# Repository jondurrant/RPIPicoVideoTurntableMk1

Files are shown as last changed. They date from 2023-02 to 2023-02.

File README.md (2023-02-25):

# RPIPicoVideoTurntableMk1
RPI Pico Video Turntable Mk1. Vidio on this project is available at [https://youtube.com/@drjonea](https://youtube.com/@drjonea).

Still images are boring and when they are PCB or breadboard sometimes dificult to understand from one angle. This project is a controlled turntable for small scale video work on my projects. 

## Features

**Lighting** Uses a strip of WS2812B LEDs to illuminate the photo area. Controlled in terms of Hue, Saturation and Value.

**Calibration** Self calibrating turn table driven by a 28BYJ-48 stepper motor

**Menu** Simple menu displayed on a OLED display and controled through a Rotary Encoder.

**Sequence** Switch 1 moves the turntable to start possition by shortest route and then moves to the end possition in the direction and speed set in the configuration. Good for setup and repeat takes of the same shot

**Stop** Switch 2 stops the turntable.

**Continuous Rotation** Switch 3 provides continuous rotation and the currently configured speed. Short press is clockwise, long press is counterclockwise.

**Reset** Switch 4 resets the turntable

**Pico Reset** Switch 5 is the Pico Reset.

## Schematic and PCB

KiCad files have been included in the Schematic folder.

PDF version of the schematic is also included.

Gerb files are included in the PCB folder 

## 3D Models

OpenSCAD project is in the folder 3DModels. You will need two supporting libraries.

Download [gears.scad](https://www.thingiverse.com/thing:4194148/files)

Download [stepper.scad](https://www.thingiverse.com/thing:4031757/files)

## Libraries

+ [FreeRTOS Kernel](https://github.com/FreeRTOS/FreeRTOS-Kernel)
+ [PicoLED](https://github.com/ForsakenNGS/PicoLED)
+ [pico-ssd1306](https://github.com/daschr/pico-ssd1306)

## Clone and Build

```
git clone --recurse-submodules https://github.com/jondurrant/RPIPicoVideoTurntableMk1
cd RPIPicoVideoTurntableMk1
mkdir build
cd build
cmake ..
make
```

## Links

+ Further YouTube projects on my channel [YouTube @DrJonEa](https://youtube.com/@drjonea).
+ Blogs at [DrJonEa.co.uk](https://drjonea.co.uk/IoT)
+ RPI Pico Courses at [Udemy @DrJonEa](https://drjonea.co.uk/training/)

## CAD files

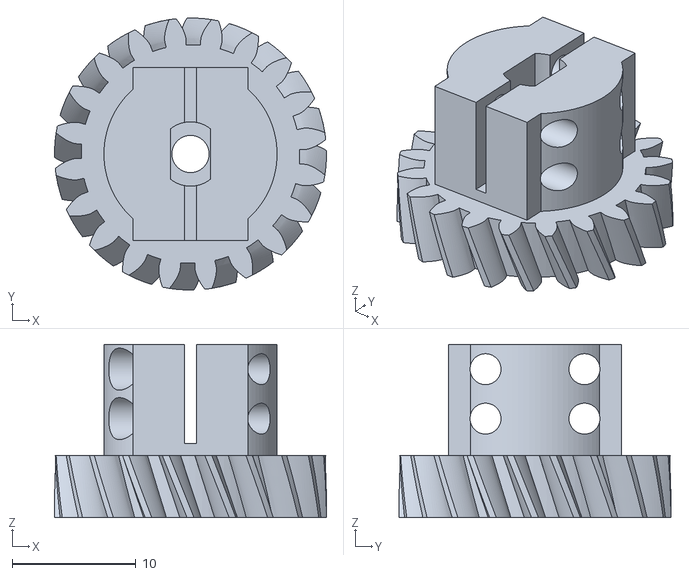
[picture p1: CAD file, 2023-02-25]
3DModels/driveCog.stl
22.0 x 22.0 x 14.0

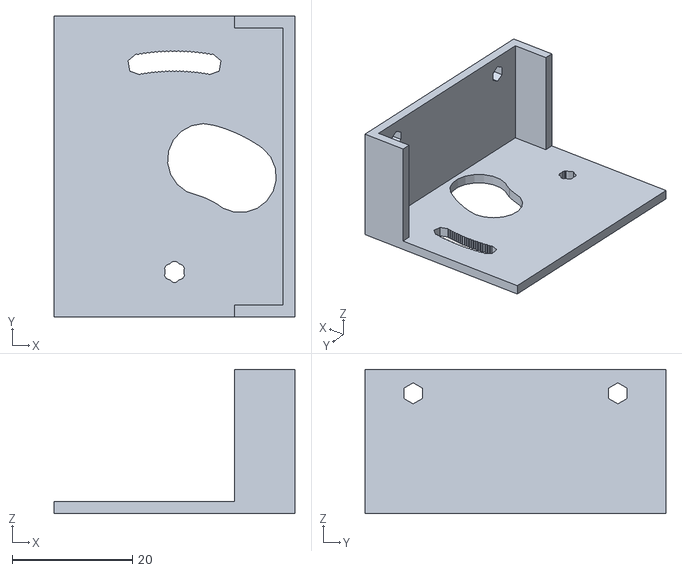
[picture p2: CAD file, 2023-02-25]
3DModels/motorMount.stl
40.0 x 50.0 x 24.0

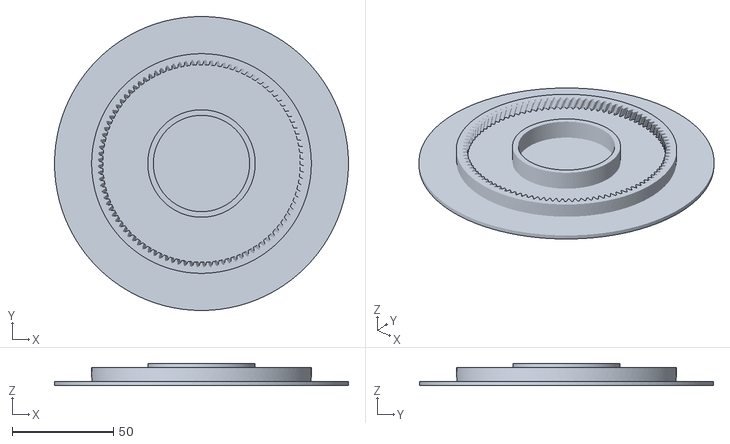
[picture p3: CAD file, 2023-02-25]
3DModels/table.stl
145.0 x 145.0 x 11.0

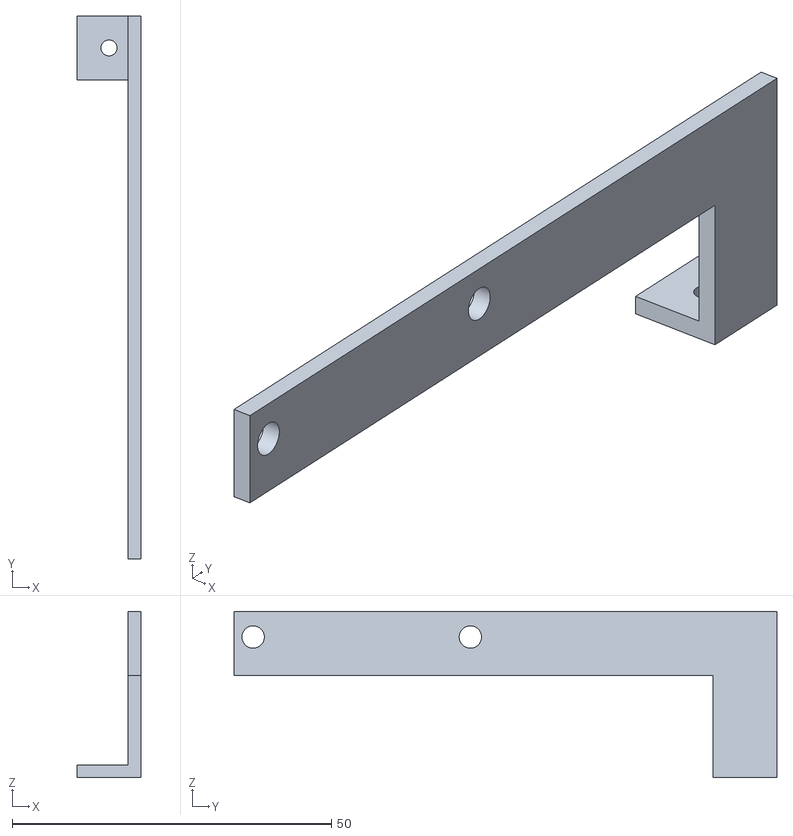
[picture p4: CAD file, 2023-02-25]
3DModels/sensorBracket.stl
10.0 x 85.0 x 26.0

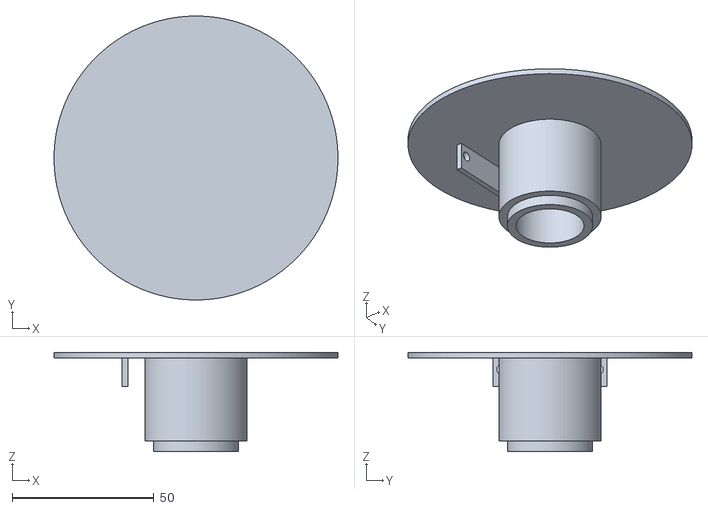
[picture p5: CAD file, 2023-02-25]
3DModels/base.stl
100.0 x 100.0 x 35.0

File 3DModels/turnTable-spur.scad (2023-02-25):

use <gears.scad>
use <stepper.scad>

THICK = 2;
M5=5.5;
M4=4.5;
M3=3.5;
M2=2.5;
M3INSERT=3.7;
M2INSERT=3.4;


Module = 1;
width = 5.0; // 0.01
teeth = 30;
bore = 3; // 0.01
straight = false;

/* [Advanced Parameters] */
hub = true;
hub_diameter = 6; // 0.01
hub_thickness = 5; // 0.01
// (Weight optimization if applicable)
optimized = false;
pressure_angle = 20; // 0.01
helix_angle = 20; // 0.01
clearance = 0.05; // 0.01

/* [Multi-gear configurations] */
idler_teeth = 100;//36;
idler_bore = 3; // 0.01
assembled = true;

/* [Rack parameters] */
rack_length = 50; // 0.01
rack_height = 4; // 0.01

/* [Worm parameters] */
// Worm lead angle                                                                (For final worm diameter, see also number of starts.)
lead_angle = 4; // 0.01
// Number of starts                                                                (For final worm diameter, see also lead angle.)
worm_starts = 1;
// Worm bore                                             (Please note: The bore in Basic Gear Parameters is used for the bore of the worm gear, not the worm.)
worm_bore = 3; // 0.01
worm_length = 6; // 0.01

/* [Bevel gear parameters] */
bevel_angle = 45; // 0.01
bevel_width = 5; // 0.01
shaft_angle = 90; // 0.01

/* [Annular/internal gear parameters] */
rim_width = 3; // 0.01

/* [Planetary gear parameters] */
solar_teeth = 20;
planet_teeth = 10;
number_of_planets = 3;


module customizer_separator() {}

finalHelixAngle = straight ? 0 : helix_angle;
final_hub_diameter = hub ? hub_diameter : 0;
final_hub_thickness = hub ? hub_thickness : 0;

$fn = 96;

/*
 stirnrad (modul=Module, zahnzahl=teeth, breite=width, bohrung=bore, nabendurchmesser=final_hub_diameter, nabendicke=final_hub_thickness, eingriffswinkel=pressure_angle, schraegungswinkel=finalHelixAngle, optimiert=optimized);

*/


/*
kegelrad(modul=Module, zahnzahl=teeth,  teilkegelwinkel=bevel_angle, zahnbreite=bevel_width, bohrung=bore, eingriffswinkel=pressure_angle, schraegungswinkel=finalHelixAngle);

*/

/*
kegelradpaar(modul=Module, zahnzahl_rad=idler_teeth, zahnzahl_ritzel=teeth, achsenwinkel=shaft_angle, zahnbreite=bevel_width, bohrung_rad=idler_bore, bohrung_ritzel=bore, eingriffswinkel=pressure_angle, schraegungswinkel=finalHelixAngle, zusammen_gebaut=assembled);
*/

//cylinder(h=1, d=100, center=true);



mainBearing=[30,47,9];
baseH=40;




driveCog();

color("#A0FFA0")motorMount();
table();
color("#A0A0FF")base();

translate([0,0, mainBearing[2]/2])bearing30x47x9();
motor();


sensor();




//Test outer bearing
/*
intersection(){
    table();
    cylinder(d=60, h= 30, center=true);
}
*/


//Test inner bearing

/*
intersection(){
    base();
    cylinder(d=100, h= 30, center=true);
}
*/



module bearing30x47x9(){
    color("#505050"){
        difference(){
            cylinder(d=mainBearing[1], h = mainBearing[2], center=true);
            cylinder(d=mainBearing[0], h = mainBearing[2]*2, center=true);
        }
    }
}


module driveCog(){
    driveTeeth = 20;
    translate([-39,0,1]){
        stirnrad (modul=Module, zahnzahl=driveTeeth, breite=width, bohrung=bore, nabendurchmesser=final_hub_diameter, nabendicke=0, eingriffswinkel=pressure_angle, schraegungswinkel=finalHelixAngle, optimiert=optimized);
    }
    
    translate([-39,-8,18]){
        rotate([0,180,0])
            hub_28byj48();
    }
}




module table(){
    bearingShrink=0.5;
    translate([0,0,0])
        hohlrad (modul=Module, zahnzahl=idler_teeth, breite=width, randbreite=rim_width, eingriffswinkel=pressure_angle, schraegungswinkel=finalHelixAngle);
    
    translate([0,0,THICK/-2-2])
            cylinder(h=THICK, d=145, center=true);
    
    translate([0,0,THICK/-2])
        difference(){
            cylinder(h=THICK, d=108, center=true);
            cylinder(h=THICK*3, d=106, center=true);
        }
    
    
    difference(){
        translate([0,0,mainBearing[2]/2-2])
            cylinder(h=mainBearing[2], d=mainBearing[1]+THICK*3, center=true);
        cylinder(d=mainBearing[1]+ bearingShrink, h=mainBearing[2]*4, center=true);
    }
         
}




module motor(){
    
    //translate([-39+8,0,18]){
    translate([-39-8,0,18]){

        rotate([0, 0,0]) rotate([0,0,-90]) stepper_28byj48();
    }
}


module cutout_28byj48(){
    //Side M3 Bolts
    for (i=[-1, 1]){
        translate([17.5 * i,0,0]){
            cylinder(d=M3, h=THICK*3, center=true);
        }
    }
    
    translate([0,8,0]){
        cylinder(d=12, h=THICK*3, center=true);
    }
}


module hub_28byj48(){
    spindleD = 5.2;
    spindleX = 3.2;
    hubLen = 10;
    hubDiam = 14;
    translate([0, 8, THICK*1.5 + hubLen/2]){
        difference(){
            union(){
                cylinder(d=hubDiam, h=hubLen, center=true);
                cube([hubDiam/1.5, hubDiam , hubLen], center=true);
            }
            
            //Shaft
            intersection(){
                cylinder(d=spindleD, h=hubLen+THICK, center=true);
                cube([spindleX, hubDiam,hubLen+THICK], center=true);
            }
            
        
        
            // M2 Holes
            for (i=[-1,1]){
                translate([0, i*4, -3]){
                    rotate([0,90,0]) {
                        cylinder(d=M2, h= hubDiam *2, center=true);
                        translate([0,0,hubDiam/2])
                            cylinder(d=M2INSERT, 8, center=true);
                    }
                }
                translate([0, i*4, 1]){
                    rotate([0,90,0]){
                        cylinder(d=M2, h= hubDiam *2, center=true);
                        translate([0,0,hubDiam/2])
                            cylinder(d=M2INSERT, 8, center=true);
                    }
                }
            }
            
            
            //Slot
            translate([0,0,-2]){
                cube([1, hubDiam*1.5, hubLen], center=true);
            }
            
        }
        
    }
}


module base(){
    edge = [-34.5,0,45-18];
    bearingShrink=0;
    
    
    
    //Base Plate
    translate([0,0,baseH]) {
        cylinder(h=THICK, d=100, center=true);
    }
    
    //Mainbearing Post
    translate([0,0,(baseH + mainBearing[2])/2-THICK]){
        difference(){
            //Outer Wall
            cylinder(d=mainBearing[0]+THICK*3, h = baseH - mainBearing[2] + THICK, center=true);
            //Seat
            translate([0,0,baseH/-2+THICK*2.5]) difference(){
                cylinder(d=mainBearing[1]+THICK*2, h = mainBearing[2]/2, center=true);
                cylinder(d=mainBearing[0]-bearingShrink, h = mainBearing[2]/2, center=true);
            }
            
            //Inner
            cylinder(d=mainBearing[0]-THICK*3, h = baseH *2, center=true);
        }
    }
    
    
    //Motor Plate
    translate([-47,0, baseH]) {
        translate([22,0,(10+THICK)/(-2)]){
            difference(){
                cube([THICK, 40, 10], center=true);
                for (y=[-17,17])translate([0,y,1]){
                    rotate([0,90,0])
                        cylinder(d=M3, h=THICK*4, center=true);
                }
            }
        }
    }
   
}

module motorMount(){
    
    
    //Motor Mount
    motorH=24;
    translate([-47,0, baseH]) {
        translate([0,0,(motorH+THICK)/(-2)]){
            difference(){
                cube([40,50,motorH], center=true);
                translate([THICK*-1,0,THICK]){
                    cube([40,50-THICK*2,motorH], center=true);
                }
                translate([THICK*-5,0,THICK]){
                    cube([40,55-THICK*2,motorH], center=true);
                }
                
                translate([0,0,motorH/(-2)]){
                    rotate([0,0,-90]){
                        cutout_28byj48();
                        for (i=[-10:1:10]){
                            rotate_about([0,0,i],p=[17.5,0,0]){
                                cutout_28byj48();
                            }
                        }
                    }
                }
                
                //Bolt holes
                translate([40/2,0,motorH/(2) - THICK*2]){
                    for (y=[-17,17])translate([0,y,0]){
                        rotate([0,90,0])
                            cylinder(d=M3, h=THICK*4, center=true);
                    }
                }
            }
        }
    }
}

module rotate_about(a, v, p=[0,0,0]) {
     translate(p) rotate(a,v) translate(-p) children();
}


module m4Spacer(){
    difference(){
        cylinder(d=7, h=4, center=true);          
        cylinder(d=M4, h=40, center=true);     
    }
}
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

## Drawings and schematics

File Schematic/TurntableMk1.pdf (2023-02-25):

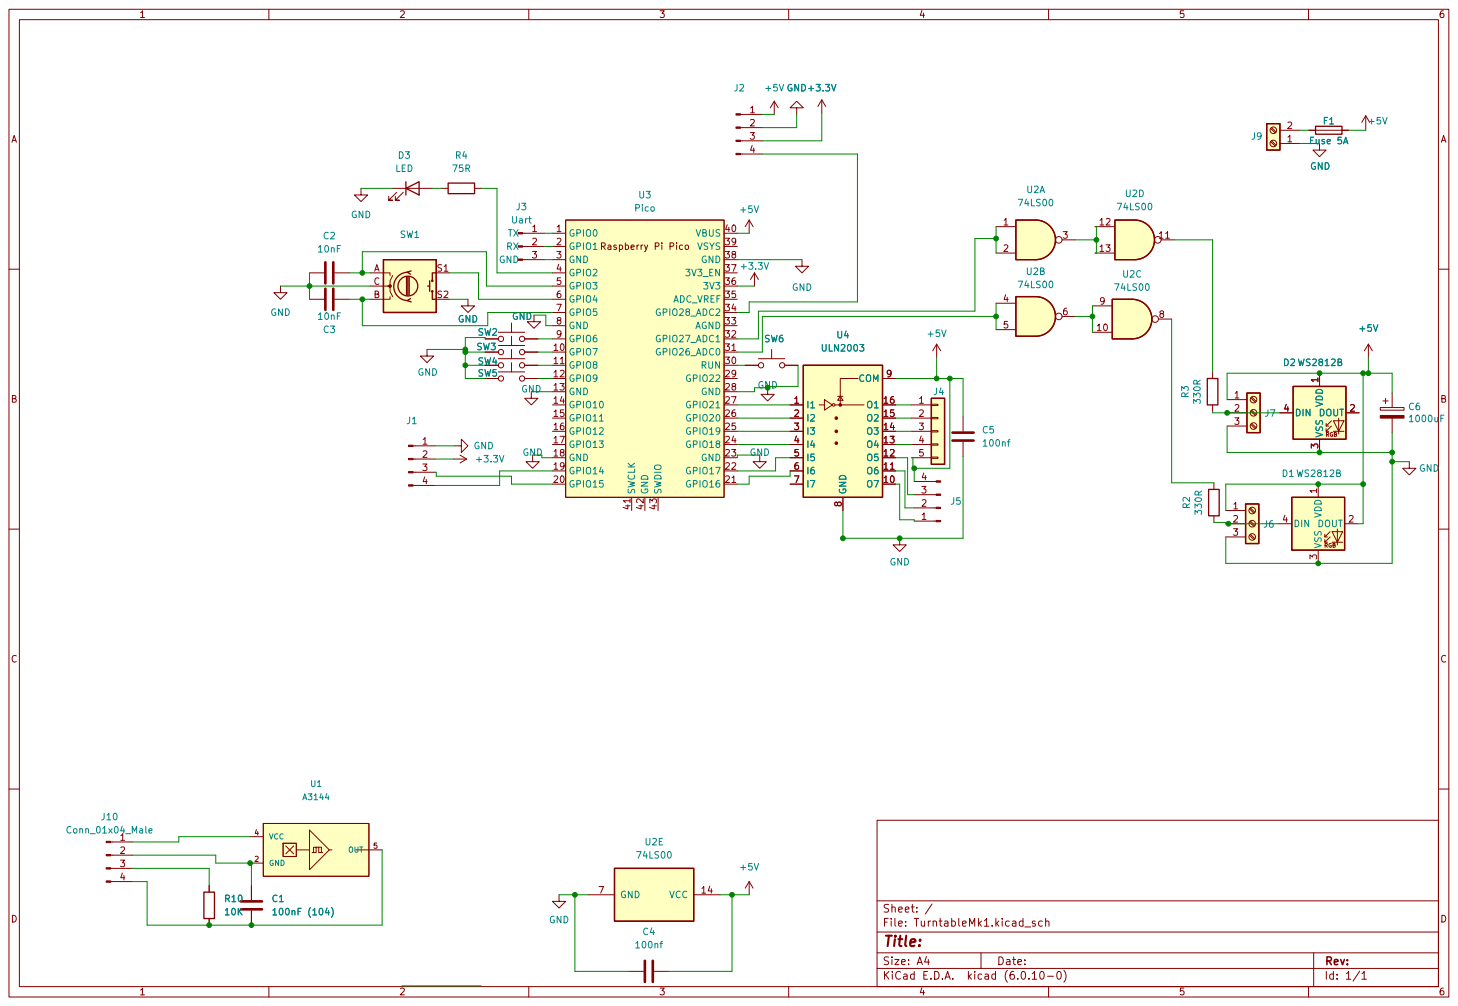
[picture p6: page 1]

I4 4 | 4
I5 5 | 5

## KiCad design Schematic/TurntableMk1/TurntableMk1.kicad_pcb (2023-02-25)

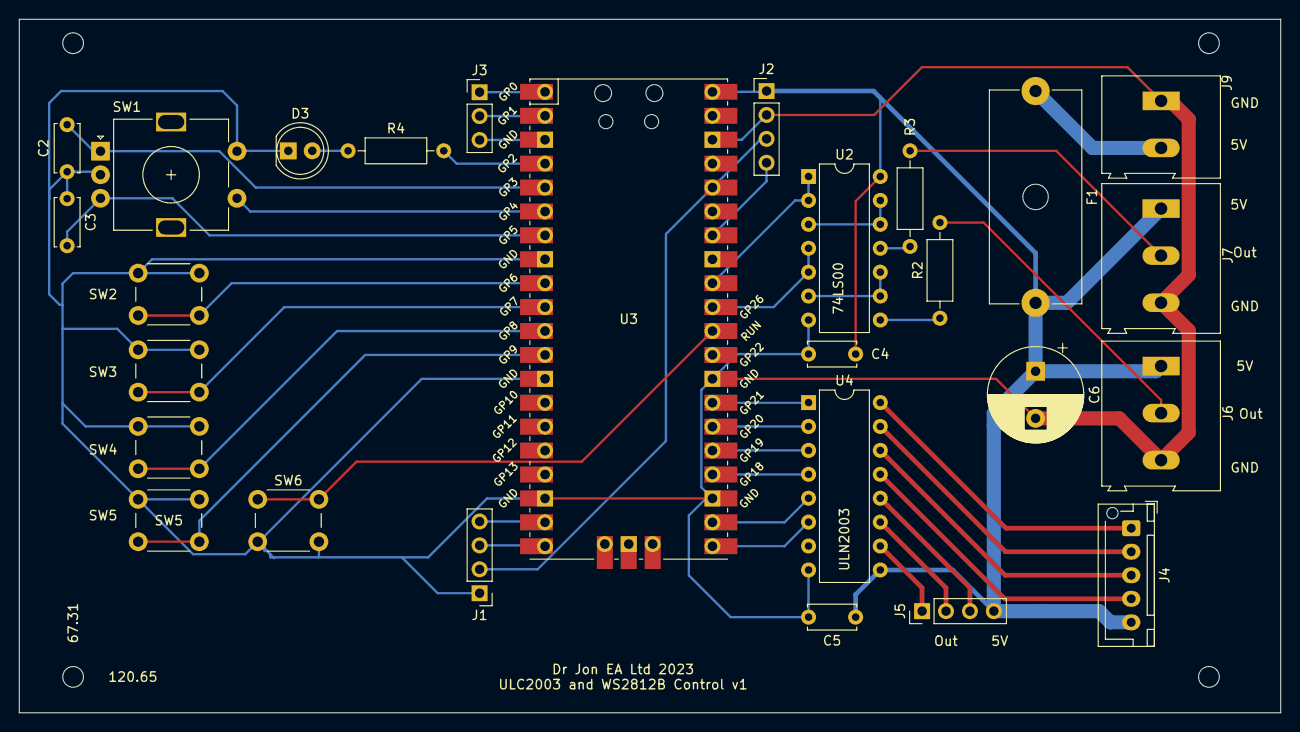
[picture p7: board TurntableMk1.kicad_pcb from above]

Board: 2 copper layers, 134.0 x 73.7 mm, 27 parts (0 on the bottom side), 41 nets.

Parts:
C2, C3: 10nF; C_Disc_D5.0mm_W2.5mm_P5.00mm
C4, C5: 100nf; C_Disc_D5.0mm_W2.5mm_P5.00mm
C6: 1000uF; CP_Radial_D10.0mm_P5.00mm
D3: LED; LED_D5.0mm
F1: Fuse 5A; Fuseholder_Cylinder-5x20mm_Schurter_0031_8201_Horizontal_Op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
J1, J2, J5: Conn_01x04_Male; PinHeader_1x04_P2.54mm_Vertical
J3: Uart; PinHeader_1x03_P2.54mm_Vertical
J4: Conn_01x05; JST_XH_B5B-XH-AM_1x05_P2.50mm_Vertical
J6, J7: Screw_Terminal_01x03; TerminalBlock_Altech_AK300-3_P5.00mm
J9: Screw_Terminal_01x02; TerminalBlock_Altech_AK300-2_P5.00mm
R2, R3: 330R; R_Axial_DIN0207_L6.3mm_D2.5mm_P10.16mm_Horizontal
R4: 75R; R_Axial_DIN0207_L6.3mm_D2.5mm_P10.16mm_Horizontal
SW1: RotaryEncoder_Switch; RotaryEncoder_Alps_EC11E-Switch_Vertical_H20mm
SW2, SW3, SW4, SW5, SW6: SW_Push; SW_PUSH_6mm
U2: 74LS00; DIP-14_W7.62mm
U3: Pico; RPi_Pico_SMD_TH
U4: ULN2003; DIP-16_W7.62mm

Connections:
+3.3V: J1.2, J2.3, U3.36 (3V3)
+5V: C4.1, C5.1, C6.1, F1.2, J2.1, J4.5, J5.4, J6.1, J7.1, U2.14 (VCC), U3.40 (VBUS), U4.9 (COM)
GND: C2.1, C3.1, C4.2, C5.2, C6.2, D3.1 (K), J1.1, J2.2, J6.3, J7.3, J9.1, SW1.C, SW1.S2, SW2.1, SW3.1, SW4.1, SW5.1, SW6.2, U2.7 (GND), U3.8 (GND), U3.13 (GND), U3.18 (GND), U3.23 (GND), U3.28 (GND), U3.38 (GND), U4.8 (GND)
unnamed: C2.2, SW1.A, U3.5 (GPIO3)
unnamed: C3.2, SW1.B, U3.7 (GPIO5)
unnamed: J6.2, R2.2
unnamed: J7.2, R3.2
unnamed: D3.2 (A), R4.1
unnamed: F1.1, J9.2
unnamed: J1.3, U3.20 (GPIO15)
unnamed: J3.1 (TX), U3.1 (GPIO0)
unnamed: J3.2 (RX), U3.2 (GPIO1)
unnamed: J3.3 (GND), U3.3 (GND)
unnamed: J4.1, U4.16 (O1)
unnamed: J4.2, U4.15 (O2)
unnamed: J4.3, U4.14 (O3)
unnamed: J4.4, U4.13 (O4)
unnamed: J5.1, U4.10 (O7)
unnamed: J5.2, U4.11 (O6)
unnamed: J5.3, U4.12 (O5)
unnamed: R2.1, U2.8
unnamed: R3.1, U2.11
unnamed: R4.2, U3.4 (GPIO2)
unnamed: SW1.S1, U3.6 (GPIO4)
unnamed: SW2.2, U3.9 (GPIO6)
unnamed: SW3.2, U3.10 (GPIO7)
unnamed: SW4.2, U3.11 (GPIO8)
unnamed: SW5.2, U3.12 (GPIO9)
unnamed: SW6.1, U3.30 (RUN)
unnamed: U2.1, U2.2, U3.32 (GPIO27_ADC1)
unnamed: U2.4, U2.5, U3.31 (GPIO26_ADC0)
unnamed: U2.6, U2.9, U2.10
unnamed: U2.3, U2.12, U2.13
unnamed: J1.4, U3.19 (GPIO14)
unnamed: U3.21 (GPIO16), U4.6 (I6)
unnamed: U3.22 (GPIO17), U4.5 (I5)
unnamed: U3.24 (GPIO18), U4.4 (I4)
unnamed: U3.25 (GPIO19), U4.3 (I3)
unnamed: U3.26 (GPIO20), U4.2 (I2)
unnamed: U3.27 (GPIO21), U4.1 (I1)
unnamed: J2.4, U3.34 (GPIO28_ADC2)

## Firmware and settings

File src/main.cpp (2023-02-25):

/***
 * Control Turntable and Led Lights
 *
 * Uses FreeRTOS Task
 * Jon Durrant
 * 15-Aug-2022
 */


#include "pico/stdlib.h"

#include "FreeRTOS.h"
#include "task.h"
#include <stdio.h>

#include "BlinkAgent.h"
#include "Stepper28BYJ.h"

#include <PicoLed.hpp>
#include "OledDisplay.h"

#include "RotEncListener.h"
#include "RotEncAgent.h"

#include "UI.h"


//Standard Task priority
#define TASK_PRIORITY		( tskIDLE_PRIORITY + 1UL )

//LED PAD to use
#define LED_PAD			2
#define LEDS_PAD		27

//Rotary Encoder
#define ROTENC_SW_PAD	4
#define ROTENC_A_PAD	3
#define ROTENC_B_PAD	5
#define ROTENC_COUNT	20


//Switches
#define SW1_PAD			6
#define SW2_PAD			7
#define SW3_PAD			8
#define SW4_PAD			9


//OLED I2C
#define OLED_SDA_PAD	14
#define OLED_SDL_PAD	15

//Stepper
#define STEPPER_A_PAD		18
#define STEPPER_B_PAD		19
#define STEPPER_C_PAD		20
#define STEPPER_D_PAD		21
#define STEPPER_HALL_PAD	28

/***
 * Debug function to look at Task Stats
 */
void runTimeStats(   ){
	TaskStatus_t *pxTaskStatusArray;
	volatile UBaseType_t uxArraySize, x;
	unsigned long ulTotalRunTime;


   // Get number of takss
   uxArraySize = uxTaskGetNumberOfTasks();
   printf("Number of tasks %d\n", uxArraySize);

   //Allocate a TaskStatus_t structure for each task.
   pxTaskStatusArray = (TaskStatus_t *)pvPortMalloc( uxArraySize * sizeof( TaskStatus_t ) );

   if( pxTaskStatusArray != NULL ){
      // Generate raw status information about each task.
      uxArraySize = uxTaskGetSystemState( pxTaskStatusArray,
                                 uxArraySize,
                                 &ulTotalRunTime );

	 // Print stats
	 for( x = 0; x < uxArraySize; x++ )
	 {
		 printf("Task: %d \t cPri:%d \t bPri:%d \t hw:%d \t%s\n",
				pxTaskStatusArray[ x ].xTaskNumber ,
				pxTaskStatusArray[ x ].uxCurrentPriority ,
				pxTaskStatusArray[ x ].uxBasePriority ,
				pxTaskStatusArray[ x ].usStackHighWaterMark ,
				pxTaskStatusArray[ x ].pcTaskName
				);
	 }


      // Free array
      vPortFree( pxTaskStatusArray );
   } else {
	   printf("Failed to allocate space for stats\n");
   }

   //Get heap allocation information
   HeapStats_t heapStats;
   vPortGetHeapStats(&heapStats);
   printf("HEAP avl: %d, blocks %d, alloc: %d, free: %d\n",
		   heapStats.xAvailableHeapSpaceInBytes,
		   heapStats.xNumberOfFreeBlocks,
		   heapStats.xNumberOfSuccessfulAllocations,
		   heapStats.xNumberOfSuccessfulFrees
		   );
}


/***
 * Main task to boot the other Agents
 * @param params - unused
 */
void mainTask(void *params){
	BlinkAgent blink(LED_PAD);

	printf("Boot task started\n");


	blink.start("Blink", TASK_PRIORITY);


	Stepper28BYJ stepper(
			STEPPER_A_PAD,
			STEPPER_B_PAD,
			STEPPER_C_PAD,
			STEPPER_D_PAD,
			STEPPER_HALL_PAD);
	stepper.start("Stepper", TASK_PRIORITY+1);


	auto ledStrip = PicoLed::addLeds<PicoLed::WS2812B>(pio0, 0, LEDS_PAD, 10, PicoLed::FORMAT_GRB);
	ledStrip.setBrightness(255);
	ledStrip.fill( PicoLed::RGB(255, 0, 0) );
	ledStrip.show();


	RotEncAgent rotEnc(
			ROTENC_SW_PAD,
			ROTENC_A_PAD,
			ROTENC_B_PAD,
			ROTENC_COUNT);
	rotEnc.start("RotEnc", TASK_PRIORITY);


	//UI
	UI ui;
	ui.initRotEnc(&rotEnc);
	ui.initSws(
			SW1_PAD,
			SW2_PAD,
			SW3_PAD,
			SW4_PAD);
	ui.initStepper(&stepper);
	ui.initOled(
			OLED_SDA_PAD,
			OLED_SDL_PAD);
	ui.initLeds(&ledStrip);
	ui.start("UI", TASK_PRIORITY);



	for (;;){
		vTaskDelay(3000);
	}


}




/***
 * Launch the tasks and scheduler
 */
void vLaunch( void) {

	//Start blink task
    TaskHandle_t task;
    xTaskCreate(mainTask, "MainThread", 500, NULL, TASK_PRIORITY, &task);

    /* Start the tasks and timer running. */
    vTaskStartScheduler();
}

/***
 * Main
 * @return
 */
int main( void )
{
	//Setup serial over USB and give a few seconds to settle before we start
    stdio_init_all();
    sleep_ms(2000);
    printf("GO\n");

    //Start tasks and scheduler
    const char *rtos_name = "FreeRTOS";
    printf("Starting %s on core 0:\n", rtos_name);
    vLaunch();


    return 0;
}

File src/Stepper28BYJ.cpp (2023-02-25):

/*
 * Stepper28BYJ.cpp
 *
 *  Stepper Motor driven by ULN2003 driver using FreeRTOS
 *
 *
 *  Created on: 24 Dec 2022
 *      Author: jondurrant
 */

#include "Stepper28BYJ.h"
#include <cstdio>

//Structure to use for queue
enum StepperAction {StepperStep, StepperTo, StepperReset, StepperCont};
struct StepperReq {
	StepperAction action;
	int16_t steps;
	float rpm;
	bool cw;
	uint32_t id;
};
typedef struct StepperReq StepperReqT;




/***
 * Constructor
 * @param gp1 - GPIO Pad
 * @param gp2 - GPIO Pad
 * @param gp3 - GPIO Pad
 * @param gp4 - GPIO Pad
 * @param slotGP - GPIO Pad for slot detector
 */
Stepper28BYJ::Stepper28BYJ(
		uint8_t gp1,
		uint8_t gp2,
		uint8_t gp3,
		uint8_t gp4,
		uint8_t hallGP ){
	pGPPAD[0] = gp1;
	pGPPAD[1] = gp2;
	pGPPAD[2] = gp3;
	pGPPAD[3] = gp4;

	xHallGP = hallGP;

	xCmdQ = xQueueCreate( STEPPER_QUEUE_LEN, sizeof(StepperReqT));
	if (xCmdQ == NULL){
		printf("ERROR: Unable to create Queue\n");
	}
	setDelay(14);
}


/***
 * Destructor
 */
Stepper28BYJ::~Stepper28BYJ() {
	if (xCmdQ != NULL){
		vQueueDelete(xCmdQ);
	}
}

/***
 * Get the static depth required in words
 * @return - words
 */
configSTACK_DEPTH_TYPE Stepper28BYJ::getMaxStackSize(){
	return 200;
}

/***
 * Initialise the GPIO
 */
void Stepper28BYJ::init(){
	for (uint8_t i=0; i < 4; i++){
		gpio_init(pGPPAD[i]);
		gpio_set_dir(pGPPAD[i], GPIO_OUT);
		gpio_put(pGPPAD[i], 0);
	}

	gpio_init(xHallGP);
	gpio_set_dir(xHallGP, GPIO_IN);

}

/***
 * Run loop for the agent.
 */
void Stepper28BYJ::run(){

	init();


	uint8_t s;
	uint32_t id = 0;

	//printf("Stepper started\n");

	for(;;) {
		bool b = gpio_get(xHallGP);

		if (!b) {
			if (xState == StepperStartHunt){
				xState = StepperCalibrateOne;
				step(100, 14);

				//printf("Stepper moved to Calibrate %d\n", xPos);
			} else if (xState == StepperCalibrateTwo){
				//printf("Number of steps is %d\n", xPos);
				xTotalSteps = xPos;
				xState = StepperCmd;
			}

			xPos = 0;

		}

		//Stop Processing
		if (xState == StepperStop){
			xTargetPos = xPos;
			if (pObserver != NULL){
				pObserver->actionComplete(id);
			}
			xState = StepperCmd;
			id = processQueue();
		}


		if (xPos == xTargetPos){
			if (id != 0){
				//printf("Target reached %d\n", xTargetPos);
				if (pObserver != NULL){
					pObserver->actionComplete(id);
				}
				if (xState == StepperCalibrateOne){
					xState = StepperCalibrateTwo;
					stepTo(0, 14, true);
				}
			}
			id = processQueue();
		}

		if ((id != 0) && (xPos != xTargetPos)){
			doStep();
		}

		if (xState == StepperStartHunt){
			//printf("StepperStartHunt %d\n", xPos);
			doStep();
		}

		//printf("Delay(%d) would be %d\n", xSeq, xDelay[xSeq] );
		vTaskDelay(xDelay[xSeq]);
	}
}


/***
 * Do a single step on the Stepper motor in required direction.
 */
void Stepper28BYJ::doStep(){
	//uint8_t sequence[STEPPER_SEQ_LEN] = {3, 6, 12, 9};
	uint8_t sequence[STEPPER_SEQ_LEN] = {9, 12, 6, 3};

	if (xClockwise){
		xPos = modPos(xPos + 1);
		xSeq = (xSeq + 1) % STEPPER_SEQ_LEN;
	} else {
		xPos = modPos(xPos - 1);
		if (xSeq == 0){
			xSeq = 3;
		} else {
			xSeq = xSeq - 1;
		}
	}
	//printf("Pos %d Target = %d\n", xPos, xTargetPos);
	uint8_t s = sequence[xSeq];
	for (uint8_t b = 0; b < STEPPER_SEQ_LEN; b++){
		uint8_t m = 1 << b;
		if ((m & s) > 0){
			gpio_put(pGPPAD[b], 1);
		} else {
			gpio_put(pGPPAD[b], 0);
		}
	}
	//printf("%d %d %d\n", xPos, xPos % 4, s);
}

/***
 * Step motor through x full steps
 * Possitive is clockwise, negative is counter clockwise
 * @param step - Step count >0 CW, < 0 CCW
 * @param rpm - Revolutions per mininute (under 14 to work)
 * RPM 0 is maximum speed
 */
uint32_t Stepper28BYJ::step(int16_t step, float rpm){
	StepperReqT req;

	req.action = StepperStep;
	req.steps = step;
	req.rpm = rpm;
	req.id = xNextId++;

	if (xCmdQ != NULL){
		BaseType_t res = xQueueSendToBack(xCmdQ, (void *)&req, 0);
		if (res != pdTRUE){
			printf("WARNING: Queue is full\n");
		}
	}
	return req.id;
}


/***
 * Process request from the queue
 */
uint32_t Stepper28BYJ::processQueue(){
	StepperReqT req;
	float delay;

	if (xCmdQ == NULL){
		return 0;
	}

	BaseType_t res = xQueueReceive(xCmdQ, (void *)&req, 0);
	if (res == pdTRUE){
		switch(req.action){
		case StepperStep:
			xTargetPos = modPos(xPos + req.steps);
			if (req.steps < 0){
				xClockwise = false;
			} else {
				xClockwise = true;
			}

			setDelay(req.rpm);

			break;
		case StepperTo:
			xTargetPos = req.steps;
			xClockwise = req.cw;
			setDelay(req.rpm);
			break;
		case StepperCont:
			xTargetPos = -1;
			xClockwise = req.cw;
			setDelay(req.rpm);
			break;
		default:
			break;
		}

		return req.id;
	}
	return 0;
}

/***
 * Calculate the pos of stepper based on modulus maths
 * @param pos
 * @return
 */
int16_t Stepper28BYJ::modPos(int16_t pos){

	if (xState == StepperCmd){
		int16_t p = pos % xTotalSteps;
		if (p < 0){
			p = xTotalSteps + p;
		}
		return p;
	} else {
		return pos;
	}
}

/***
 * Split RPM speed as a set of four delays over the four phases
 * @param rpm - 0 will set to maximum speed
 */
void Stepper28BYJ::setDelay(float rpm){
	float delay;

	if (rpm <= 0.0){
		for (uint8_t i=0; i < STEPPER_SEQ_LEN; i++){
			xDelay[i] = DELAY;
		}
		return;
	}

	delay = (60000.0 / rpm) / (float)xTotalSteps;

	for (uint8_t i=0; i < STEPPER_SEQ_LEN; i++){
		xDelay[i] = delay;
	}

	uint16_t e = (delay * (float)STEPPER_SEQ_LEN) - xDelay[0]*STEPPER_SEQ_LEN;
	switch(e){
	case 1:
		xDelay[1]++;
		break;
	case 2:
		xDelay[1]++;
		xDelay[3]++;
		break;
	case 3:
		xDelay[1]++;
		xDelay[2]++;
		xDelay[3]++;
		break;
	}

}



/***
 * Calibrate the disk and leave at possition zero
 */
void Stepper28BYJ::calibrate(){
	xState = StepperStartHunt;
}

/***
 * Step to a possition
 * @param pos = Possition between 0 and 4047
 * @param rpm - speed, 0 to 14. 0 is max speed
 * @param cw - clockwise
 */
uint32_t Stepper28BYJ::stepTo(int16_t pos, float rpm, bool cw){
	StepperReqT req;

	req.action = StepperTo;
	req.steps = pos;
	req.rpm = rpm;
	req.cw = cw;
	req.id = xNextId++;

	if (xCmdQ != NULL){
		BaseType_t res = xQueueSendToBack(xCmdQ, (void *)&req, 0);
		if (res != pdTRUE){
			printf("WARNING: Queue is full\n");
		}
	}

	return req.id;
}

/***
 * Rotate to Degrees possition (0 to 360)
 * @param deg - Float 0 to 360
 * @param rpm - Rotation speed, under 14
 * @param cw - Clockwise or CCW.
 * @return id of the instruction
 */
uint32_t Stepper28BYJ::stepToDeg(float deg, float rpm, bool cw){
	int16_t pos = (float)xTotalSteps * (deg / 360.0);
	return stepTo(pos, rpm, cw);
}




/***
 * Set Observer
 * @param obs
 */
void Stepper28BYJ::setObserver(StepperObserver *obs){
	pObserver = obs;
}

/***
 * Get state of stepper motor
 * @return StepperCmd if in normal mode - otherwise probably calibrating
 */
StepperState Stepper28BYJ::getState(){
	return xState;
}

/***
 * Stop the current step action.
 * If another action in queue it will then start that
 */
void Stepper28BYJ::stepStop(){
	xState = StepperStop;
}
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

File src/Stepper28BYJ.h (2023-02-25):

/*
 * Stepper28BYJ.h
 *
 * Stepper Motor driven by ULN2003 driver using FreeRTOS
 *
 *  Created on: 24 Dec 2022
 *      Author: jondurrant
 */

#ifndef FREERTOS_28BYJ_48_SRC_STEPPER28BYJ_H_
#define FREERTOS_28BYJ_48_SRC_STEPPER28BYJ_H_

#include "pico/stdlib.h"
#include "FreeRTOS.h"
#include "task.h"
#include "queue.h"

#include "Agent.h"
#include "StepperObserver.h"

#define DELAY 2
#define STEPPER_QUEUE_LEN 10
#define STEPS28BYJ 2048
#define STEPPER_SEQ_LEN 4

enum StepperState {StepperCmd, StepperCalibrateOne, StepperCalibrateTwo, StepperStartHunt, StepperGotoStart, StepperStop};

class Stepper28BYJ : public Agent {
public:
	/***
	 * Constructor
	 * @param gp1 - GPIO Pad
	 * @param gp2 - GPIO Pad
	 * @param gp3 - GPIO Pad
	 * @param gp4 - GPIO Pad
	 * @param Hall Sensor - GPIO Pad for slot detector
	 */
	Stepper28BYJ(uint8_t gp1, uint8_t gp2, uint8_t gp3, uint8_t gp4, uint8_t hallGP );
	virtual ~Stepper28BYJ();

	/***
	 * Step motor through x full steps
	 * Possitive is clockwise, negative is counter clockwise
	 * @param step - Step count >0 CW, < 0 CCW
	 * @param rpm - Revolutions per mininute (under 14 to work)
	 * RPM 0 is maximum speed
	 */
	uint32_t step(int16_t step, float rpm);


	/***
	 * Calibrate the disk and leave at possition zero
	 */
	void calibrate();

	/***
	 * Step to a possition
	 * @param pos = Possition between 0 and Maximum Steps
	 * @param rpm - speed, 0 to 14. 0 is max speed
	 * @param cw - clockwise
	 */
	uint32_t stepTo(int16_t pos, float rpm, bool cw);


	/***
	 * Rotate to Degrees possition (0 to 360)
	 * @param deg - Float 0 to 360
	 * @param rpm - Rotation speed, under 14
	 * @param cw - Clockwise or CCW.
	 * @return id of the instruction
	 */
	uint32_t stepToDeg(float deg, float rpm, bool cw);

	/***
	 * Get state of stepper motor
	 * @return StepperCmd if in normal mode - otherwise probably calibrating
	 */
	StepperState getState();

	/***
	 * Get the current angle of the stepper motor
	 * @return Degrees from Hall sensor
	 */
	float getDegrees();

	/***
	 * Get Step possition. Hall sensor is possition 0
	 * Counts clockwise
	 * @return step possition
	 */
	uint16_t getPos();

	/***
	 * Stop the current step action.
	 * If another action in queue it will then start that
	 */
	void stepStop();

	/***
	 * Rotate continuously at RPM rate
	 * @param rpm - Revolutions per minute
	 * @param cw - True if clockwise
	 * @return
	 */
	uint32_t stepContinuous(float rpm, bool cw);

	/***
	 * Stop the stepper,
	 * Clear the queue of actions
	 * Return to zero possition
	 * @return
	 */
	uint32_t stepReset();

	/***
	 * Stop the stepper motor
	 * Clear the queue of actions
	 */
	void stepHaltClear();

	/***
	 * Set Observer
	 * @param obs
	 */
	void setObserver(StepperObserver *obs);

protected:

	/***
	 * Run loop for the agent.
	 */
	virtual void run();


	/***
	 * Get the static depth required in words
	 * @return - words
	 */
	virtual configSTACK_DEPTH_TYPE getMaxStackSize();

private:
	/***
	 * Initialise the GPIO
	 */
	void init();

	/***
	 * Process request from the queue
	 */
	uint32_t processQueue();

	/***
	 * Calculate the pos of stepper based on modulus maths
	 * @param pos
	 * @return
	 */
	int16_t modPos(int16_t pos);

	/***
	 * Split RPM speed as a set of four delays over the four phases
	 * @param rpm - 0 will set to maximum speed
	 */
	void setDelay(float rpm);

	/***
	 * Do a single step on the Stepper motor in required direction.
	 */
	void doStep();

	//GPIO Pads for stepper motor coils
	uint8_t pGPPAD[4];

	//Queue of commands
	QueueHandle_t xCmdQ;

	//Target possition in steps
	int16_t xTargetPos = 0;

	//Current possition in steps
	int16_t xPos = 0;

	//Total number of steps in 360, set by calibation
	int16_t xTotalSteps = STEPS28BYJ;

	//Sequence of the stepper coils (0 to 3)
	uint8_t xSeq = 0;

	//Delay to wait betweeen each step of the sequence
	uint16_t xDelay[STEPPER_SEQ_LEN];

	//Current direction
	bool xClockwise = true;

	//Hall sensor GP Pad
	uint8_t xHallGP;

	//Current observer if any
	StepperObserver *pObserver = NULL;

	//Action id for actions in the queue.
	uint32_t xNextId = 1;

	//Current state of the stepper motor. Start in calibration
	StepperState xState = StepperStartHunt;
};

#endif /* FREERTOS_28BYJ_48_SRC_STEPPER28BYJ_H_ */
